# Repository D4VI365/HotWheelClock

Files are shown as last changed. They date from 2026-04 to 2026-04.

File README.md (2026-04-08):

# HotWheels Clock
A wall clock that uses two hotwheels to idicate the time, the cars will be moved by two magnets behind the main board of the clock moved by two geared wheels with motors, all powered froma a 10000mAh battery and controlled by an esp32 in order to calibrate the time automatically via internet.

Wiring Schematic:
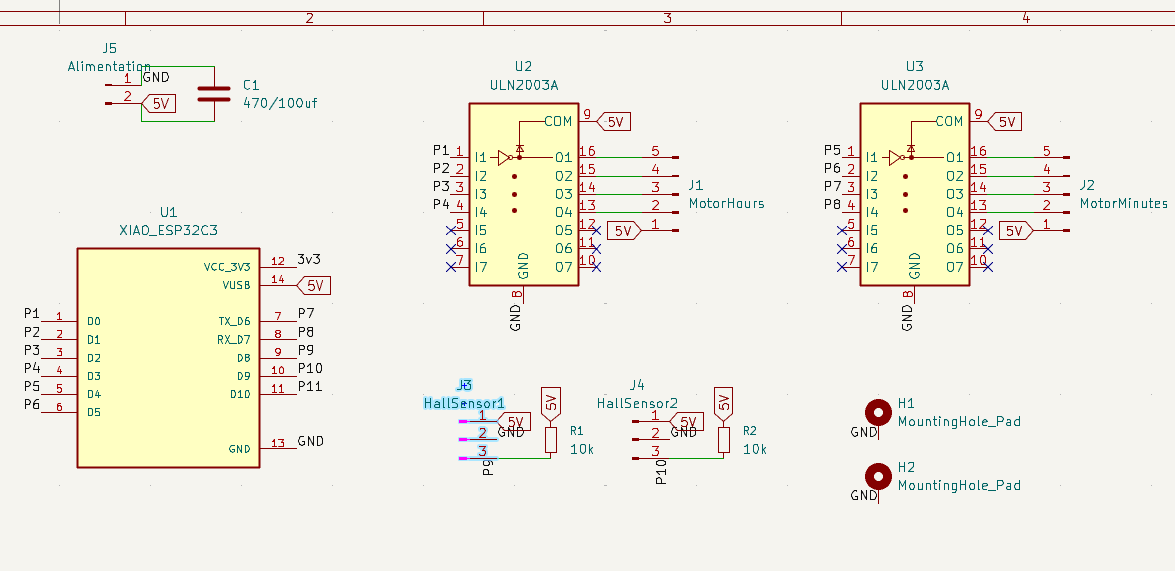
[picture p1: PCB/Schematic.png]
Schematic


PCB:
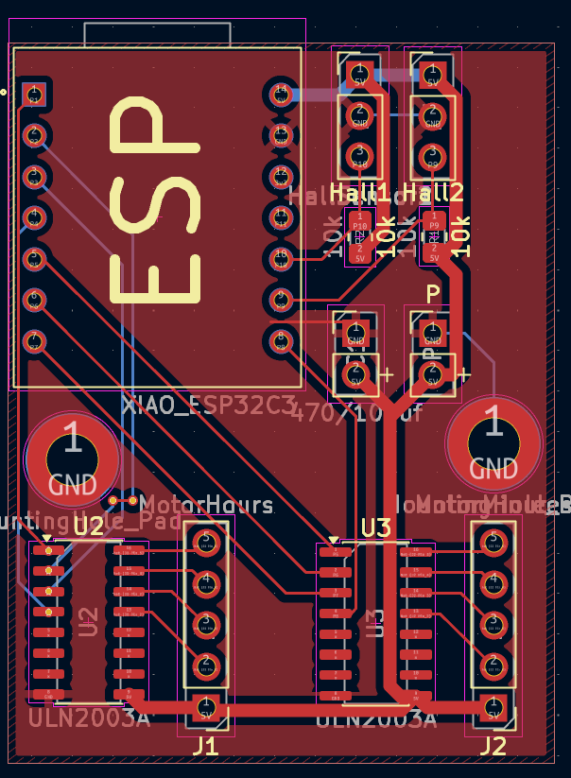
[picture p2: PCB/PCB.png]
PCB


CAD model: 
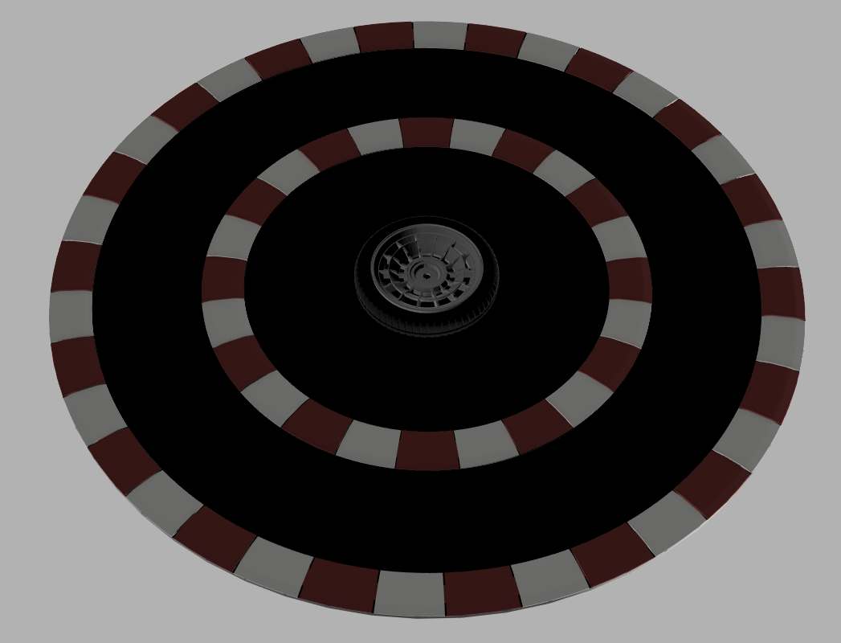
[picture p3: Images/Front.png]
Front

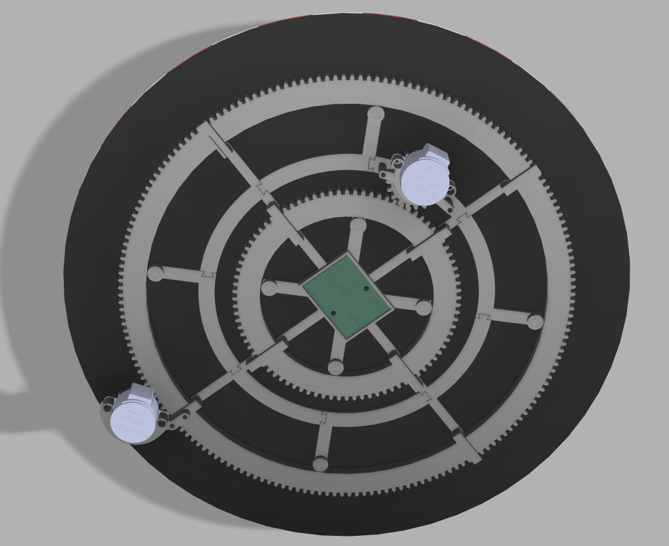
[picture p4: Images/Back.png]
Back


Print list:
1xCenterSupport
1xInnerCurb1
12xInnerCurb2
1xInnerGear
3xInnerHook
1xInnerHookHall
1xInnerMotorMount
3xMidSupport1
4xMidSupport2
1xMidSupport3
2xMotorGear
2xOuterCurb1
2xOuterCurb2
18xOuterCurb3
4xOuterGear
2xOuterHook
1xOuterHook2
1xOuterHookHall
1xOuterMotorMount
1xTyre
1xWheelRim

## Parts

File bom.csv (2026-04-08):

Component | Needed QTY | Price [$] | Link
Ball bearings | 8 | 3,73 | https://it.aliexpress.com/item/1005007668446060.html
Magnets | 8 | 3,43 | https://it.aliexpress.com/item/1005010158237241.html?mp=1
Hall Sensors | 2 | 1,73 | https://it.aliexpress.com/item/1005010291107815.html
Charger Module | 1 | 1,67 | https://it.aliexpress.com/item/1005005796829555.html
Battery | 1 | 13,64 | https://it.aliexpress.com/item/1005009333505517.html
Booster Module | 1 | 1,67 | https://it.aliexpress.com/item/1005008282461434.html
Xiao esp32 | 1 | 8,8 | https://it.aliexpress.com/item/1005008791937363.html
Stepper motor | 2 | 5,52 | https://it.aliexpress.com/item/1005008793289290.html
Motor driver | 2 | 3,08 | https://it.aliexpress.com/item/1005010300417050.html
PVC panel | 1 | 25,9 | https://pannelliplastica.it/
PCB | 1 | 6,71 | jlcpcb
Total: | 75,88

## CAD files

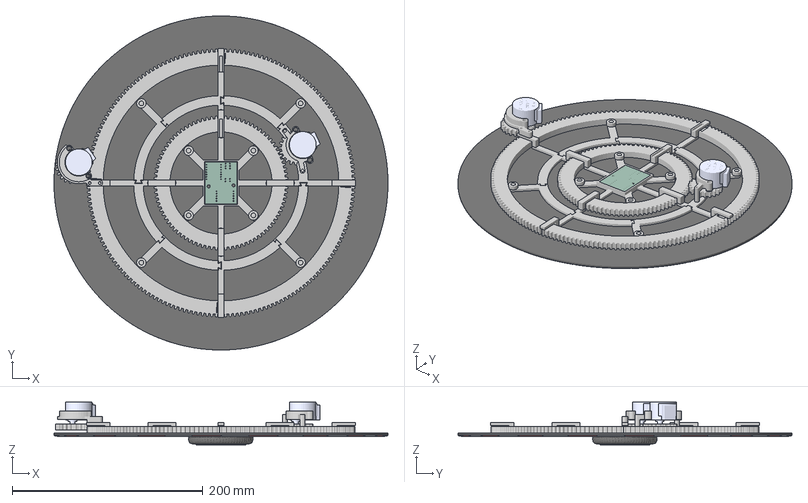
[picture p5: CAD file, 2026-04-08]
CAD/HotClock.3mf
350.0 x 350.0 x 44.9 mm
Corpo della mesh1
Corpo1 x 3
Corpo10
Corpo11
Corpo12
Corpo13
Corpo14
Corpo15
Corpo16
Corpo17
Corpo18
Corpo2 x 2
Corpo302
Corpo303
Corpo330
Corpo351
Corpo352
Corpo353
Corpo365
Corpo366
Corpo367
Corpo372
Corpo373
Corpo374
Corpo398
Corpo399
Corpo400
Corpo401
Corpo402
Corpo403
Corpo404
Corpo405
Corpo406
Corpo407
Corpo408
Corpo409
Corpo410
Corpo429
Corpo430
Corpo431
Corpo432
Corpo433
Corpo434
Corpo435
Corpo436
Corpo437
Corpo438
Corpo439
Corpo440
Corpo441
Corpo442
Corpo443
Corpo444
Corpo445
Corpo446
Corpo447
Corpo448
Corpo450
Corpo451
Corpo452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

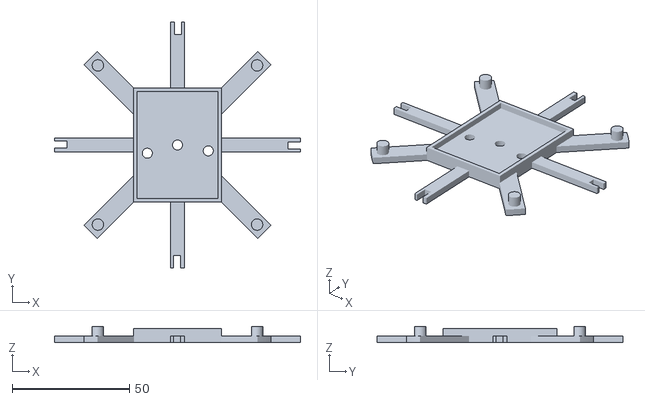
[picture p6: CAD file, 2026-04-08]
CAD/CenterSupport.stl
104.9 x 104.9 x 7.00

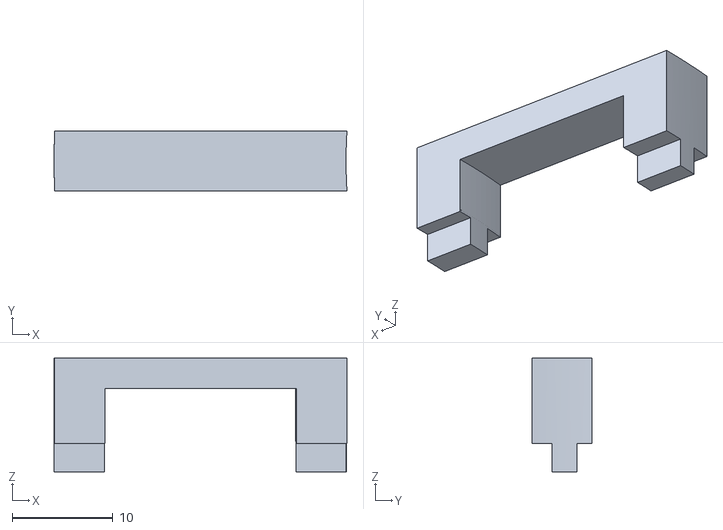
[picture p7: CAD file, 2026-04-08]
CAD/InnerHook.stl
29.1 x 6.00 x 11.3

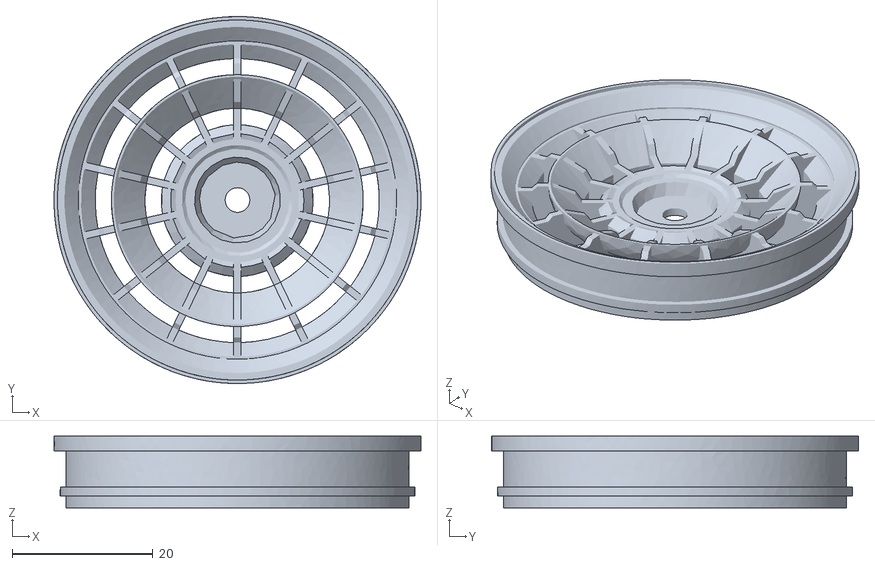
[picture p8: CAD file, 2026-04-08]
CAD/WheelRim.stl
52.2 x 52.2 x 10.2

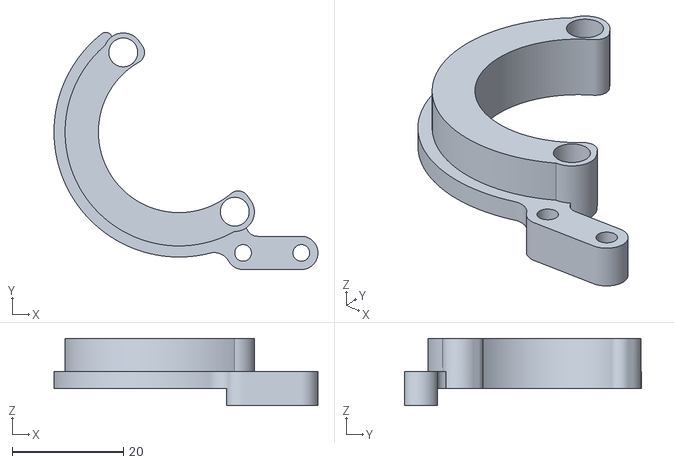
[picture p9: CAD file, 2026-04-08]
CAD/OuterMotorMount.stl
47.5 x 42.7 x 12.1

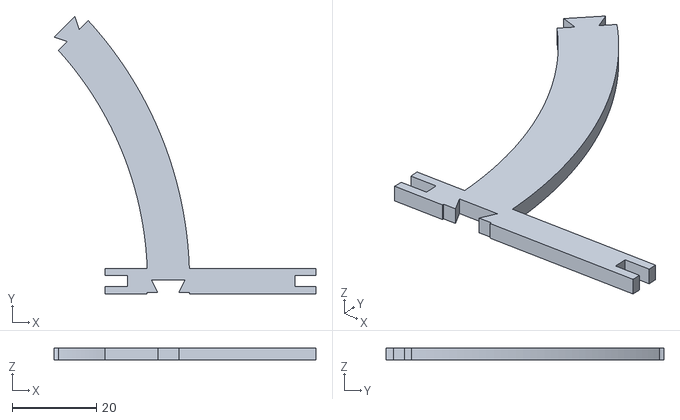
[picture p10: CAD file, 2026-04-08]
CAD/MidSupport3.stl
62.2 x 65.9 x 2.80

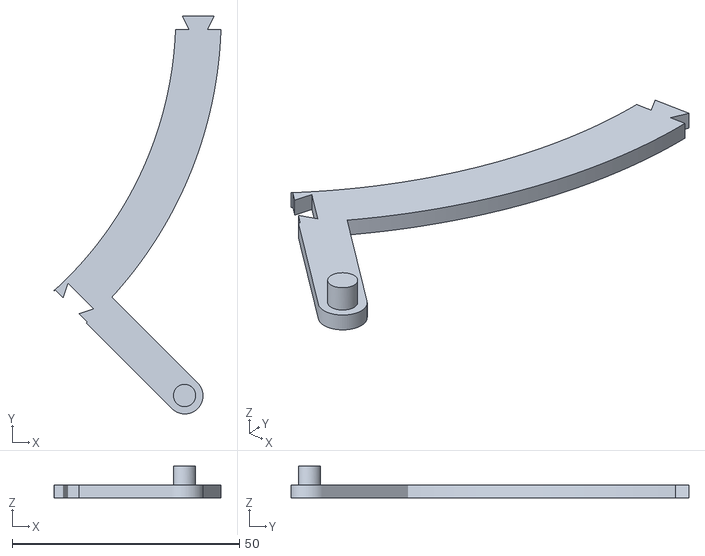
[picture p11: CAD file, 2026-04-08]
CAD/MidSupport1.stl
36.7 x 87.5 x 7.00

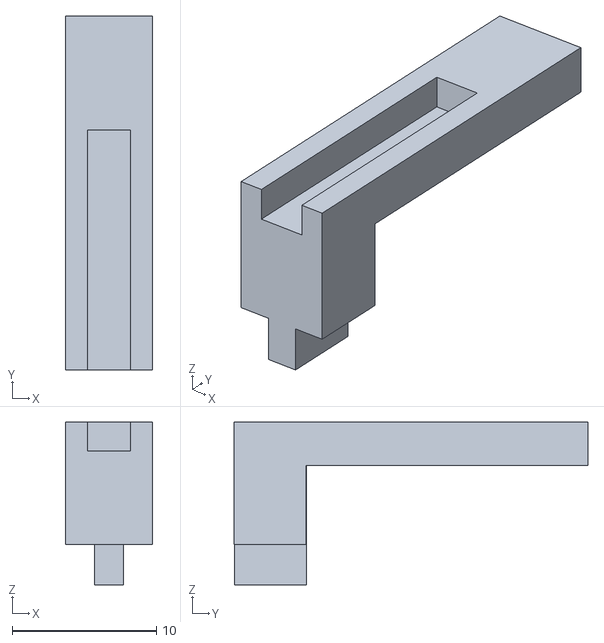
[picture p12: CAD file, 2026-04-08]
CAD/OuterHookHall.stl
6.00 x 24.5 x 11.3

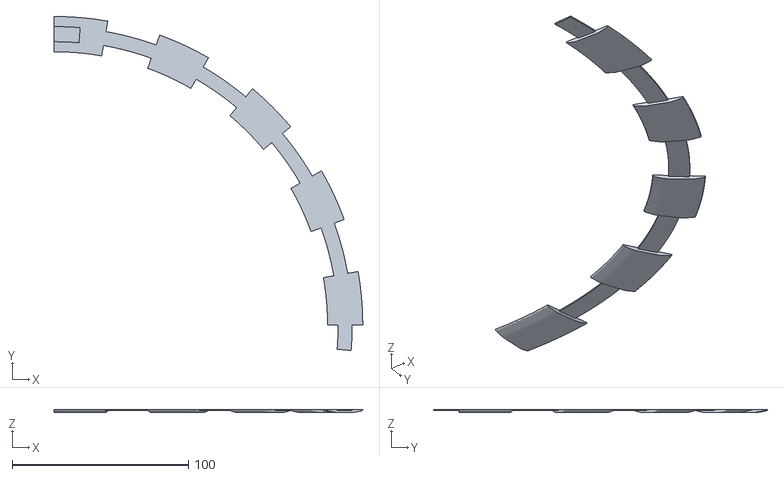
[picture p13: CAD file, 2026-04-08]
CAD/OuterCurb2.stl
175.0 x 189.4 x 1.51

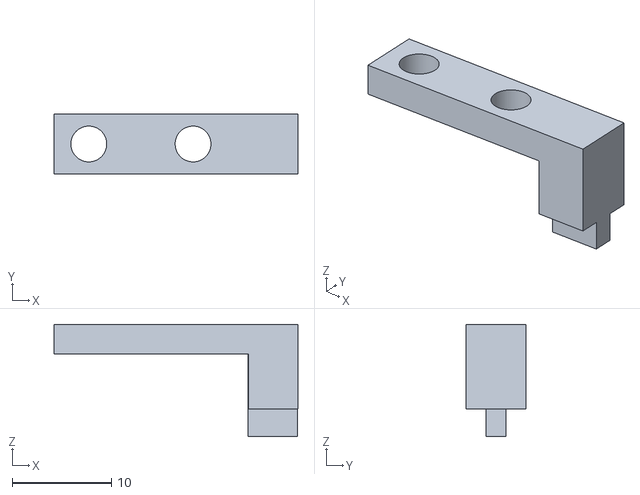
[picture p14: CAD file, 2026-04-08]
CAD/OuterHook2.stl
24.5 x 6.00 x 11.3

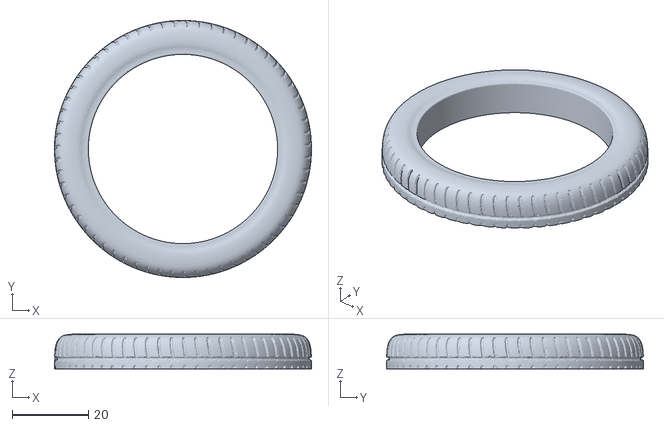
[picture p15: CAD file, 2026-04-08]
CAD/Tyre.stl
67.6 x 67.6 x 9.12

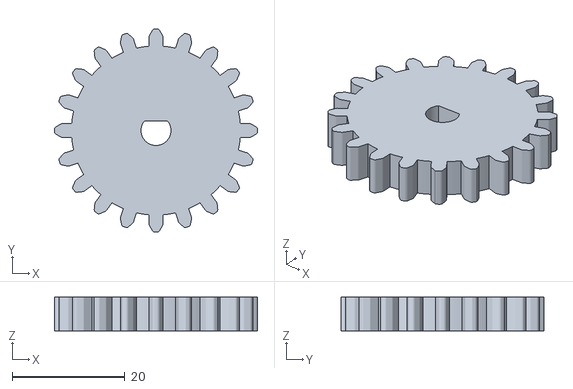
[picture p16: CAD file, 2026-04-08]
CAD/MotorGear.stl
36.0 x 36.0 x 6.00

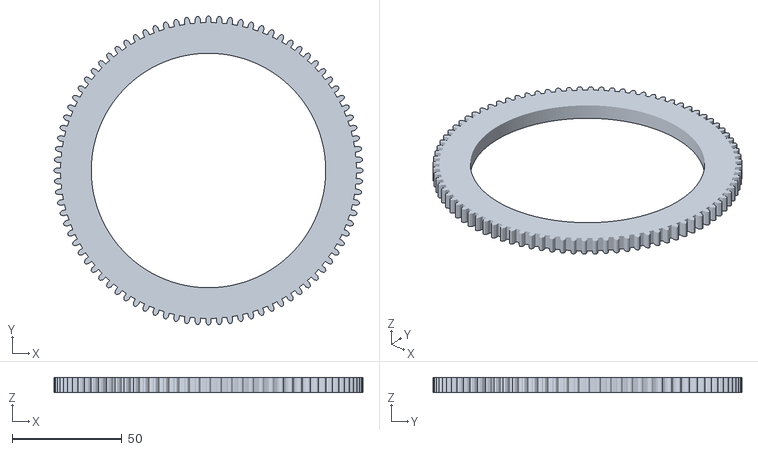
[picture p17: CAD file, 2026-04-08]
CAD/InnerGear.stl
141.0 x 141.0 x 6.80

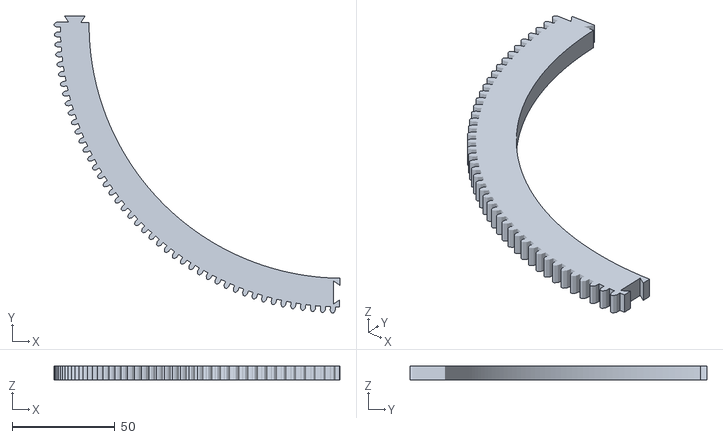
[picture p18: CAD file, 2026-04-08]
CAD/OuterGear.stl
139.1 x 144.6 x 7.00

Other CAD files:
CAD/MidSupport2.stl
CAD/InnerCurb1.stl
CAD/OuterCurb3.stl
CAD/OuterCurb1.stl
CAD/InnerCurb2.stl
CAD/InnerHookHall.stl
CAD/InnerMotorMount.stl
CAD/OuterHook.stl

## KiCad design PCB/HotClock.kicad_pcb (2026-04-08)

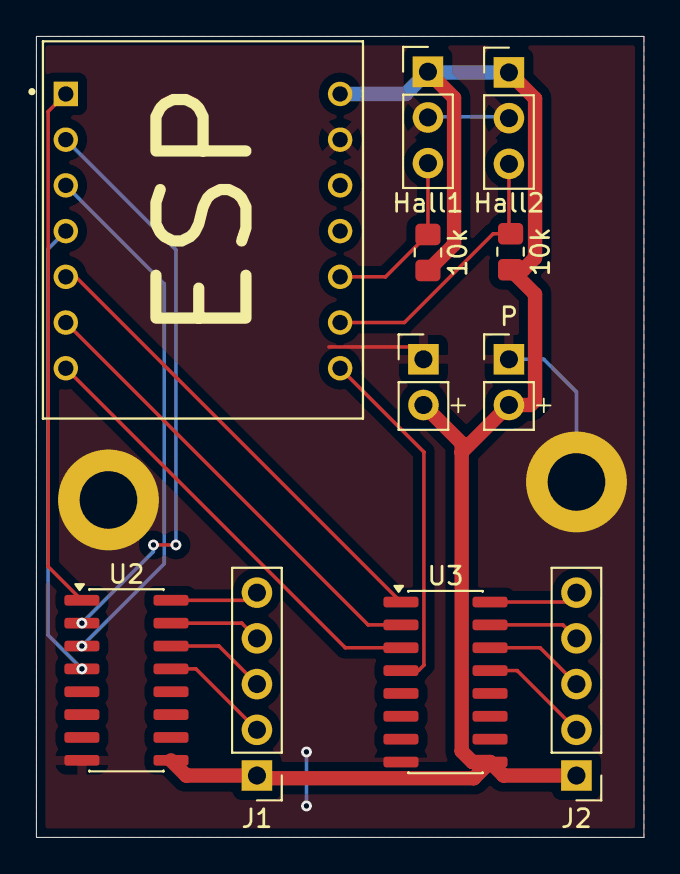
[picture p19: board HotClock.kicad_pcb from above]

Board: 2 copper layers, 33.8 x 44.5 mm, 13 parts (0 on the bottom side), 20 nets.

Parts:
10k, 10k#2: 10k; R_0805_2012Metric_Pad1.20x1.40mm_HandSolder
C1: 470/100uf; PinHeader_1x02_P2.54mm_Vertical
H1, H2: MountingHole_Pad; MountingHole_3.2mm_M3_DIN965_Pad
Hall1: HallSensor2; PinHeader_1x03_P2.54mm_Vertical
Hall2: HallSensor1; PinHeader_1x03_P2.54mm_Vertical
J1: MotorHours; PinHeader_1x05_P2.54mm_Vertical
J2: MotorMinutes; PinHeader_1x05_P2.54mm_Vertical
P: Alimentation; PinHeader_1x02_P2.54mm_Vertical
U1: XIAO_ESP32C3; MODULE_XIAO_ESP32C3
U2, U3: ULN2003A; SOIC-16_3.9x9.9mm_P1.27mm

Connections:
5V: 10k.2, 10k#2.2, C1.2, Hall1.1, Hall2.1, J1.1, J2.1, P.2, U1.14 (VUSB), U2.9 (COM), U3.9 (COM)
/GND: C1.1, H1.1, H2.1, Hall1.2, Hall2.2, P.1, U1.13 (GND), U2.8 (GND), U3.8 (GND)
/P1: U1.1 (D0), U2.1 (I1)
/P2: U1.2 (D1), U2.2 (I2)
/P3: U1.3 (D2), U2.3 (I3)
/P4: U1.4 (D3), U2.4 (I4)
/P5: U1.5 (D4), U3.1 (I1)
/P6: U1.6 (D5), U3.2 (I2)
/P7: U1.7 (TX_D6), U3.3 (I3)
/P8: U1.8 (RX_D7), U3.4 (I4)
/P9: 10k#2.1, Hall2.3, U1.9 (D8)
/P10: 10k.1, Hall1.3, U1.10 (D9)
unnamed: J1.2, U2.13 (O4)
unnamed: J1.3, U2.14 (O3)
unnamed: J1.4, U2.15 (O2)
unnamed: J1.5, U2.16 (O1)
unnamed: J2.2, U3.13 (O4)
unnamed: J2.3, U3.14 (O3)
unnamed: J2.4, U3.15 (O2)
unnamed: J2.5, U3.16 (O1)

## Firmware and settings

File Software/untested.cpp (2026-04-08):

#include <WiFi.h>
#include "time.h"
#include <AccelStepper.h>

// --- CONFIGURAZIONE WIFI ---
const char* ssid     = "IL_TUO_SSID";
const char* password = "LA_TUA_PASSWORD";
const char* ntpServer = "pool.ntp.org";
const long  gmtOffset_sec = 3600;      // Italia: UTC+1
const int   daylightOffset_sec = 3600; // Ora legale (+1h)

// --- PINOUT SCHEMA KICAD ---
#define MOTOR_H_IN1 1 
#define MOTOR_H_IN2 2 
#define MOTOR_H_IN3 3 
#define MOTOR_H_IN4 4 
#define MOTOR_M_IN1 5  
#define MOTOR_M_IN2 6  
#define MOTOR_M_IN3 7  
#define MOTOR_M_IN4 8  
#define HALL_H 9  
#define HALL_M 10 

// --- PARAMETRI MECCANICI ---
// Calcolati su: 2048 passi motore * Ratio
const float STEPS_PER_REV_H = 9011.2;  // Lancetta Ore
const float STEPS_PER_REV_M = 18432.0; // Lancetta Minuti

// Inizializzazione motori (Sequenza corretta per AccelStepper con ULN2003: 1, 3, 2, 4)
AccelStepper stepperH(AccelStepper::FULL4WIRE, MOTOR_H_IN1, MOTOR_H_IN3, MOTOR_H_IN2, MOTOR_H_IN4);
AccelStepper stepperM(AccelStepper::FULL4WIRE, MOTOR_M_IN1, MOTOR_M_IN3, MOTOR_M_IN2, MOTOR_M_IN4);

void setup() {
  Serial.begin(115200);
  
  pinMode(HALL_H, INPUT_PULLUP);
  pinMode(HALL_M, INPUT_PULLUP);

  stepperH.setMaxSpeed(800);
  stepperH.setAcceleration(400);
  stepperM.setMaxSpeed(800);
  stepperM.setAcceleration(400);

  // Connessione WiFi
  Serial.print("Connessione a "); Serial.println(ssid);
  WiFi.begin(ssid, password);
  while (WiFi.status() != WL_CONNECTED) { delay(500); Serial.print("."); }
  
  // Configura l'ora via NTP
  configTime(gmtOffset_sec, daylightOffset_sec, ntpServer);

  // Esegue l'Homing (allineamento magneti)
  Serial.println("\nHoming in corso...");
  doHoming();
}

void loop() {
  static unsigned long lastUpdate = 0;
  
  // Aggiorna la posizione target ogni secondo
  if (millis() - lastUpdate > 1000) {
    lastUpdate = millis();
    updateClockPosition();
  }

  // Muove fisicamente i motori
  stepperH.run();
  stepperM.run();
}

void doHoming() {
  // Reset Minuti
  while (digitalRead(HALL_M) == HIGH) {
    stepperM.setSpeed(-400); 
    stepperM.runSpeed();
  }
  stepperM.setCurrentPosition(0);
  stepperM.moveTo(200); // Spostamento di sicurezza fuori dal raggio del sensore
  
  // Reset Ore
  while (digitalRead(HALL_H) == HIGH) {
    stepperH.setSpeed(-400);
    stepperH.runSpeed();
  }
  stepperH.setCurrentPosition(0);
  stepperH.moveTo(200);
  
  while(stepperH.distanceToGo() != 0 || stepperM.distanceToGo() != 0) {
    stepperH.run();
    stepperM.run();
  }
}

void updateClockPosition() {
  struct tm timeinfo;
  if(!getLocalTime(&timeinfo)){
    Serial.println("Errore recupero tempo");
    return;
  }

  // Calcolo posizione target assoluta
  // Ore: (ore % 12 + minuti/60) * (passi_totali / 12)
  float hourFraction = (timeinfo.tm_hour % 12) + (timeinfo.tm_min / 60.0);
  long targetH = (long)(hourFraction * (STEPS_PER_REV_H / 12.0));

  // Minuti: (minuti + secondi/60) * (passi_totali / 60)
  float minFraction = timeinfo.tm_min + (timeinfo.tm_sec / 60.0);
  long targetM = (long)(minFraction * (STEPS_PER_REV_M / 60.0));

  stepperH.moveTo(targetH);
  stepperM.moveTo(targetM);
  
  Serial.printf("Ora: %02d:%02d:%02d -> TargetH: %ld, TargetM: %ld\n", 
                timeinfo.tm_hour, timeinfo.tm_min, timeinfo.tm_sec, targetH, targetM);
}
